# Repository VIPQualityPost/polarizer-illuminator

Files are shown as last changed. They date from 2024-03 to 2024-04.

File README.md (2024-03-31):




# Polarizer-Illuminator

A microscope illuminator that includes a liquid crystal display as a tunable polarizer. By polarizing the illuminator light, the reflected light can be filtered through a second polarizer (in this case the LCD) with specular reflections and glare removed, depending on the amount of polarization applied (based on bias across LCD). The illuminator is powered over USB PD and can be controlled via a PC for automated control in conjunctions with motorized XY stages and microscope camera. Firmware can be updated over same cable providing power thanks to DFU bootloader, just hold the button on the back and plug into a PC. 

Illuminator inspecting it's own board
| Non-polarized image | Polarized image |
| --- | --- |
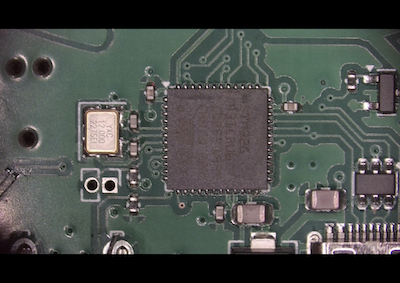
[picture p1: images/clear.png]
Image without polarization applied
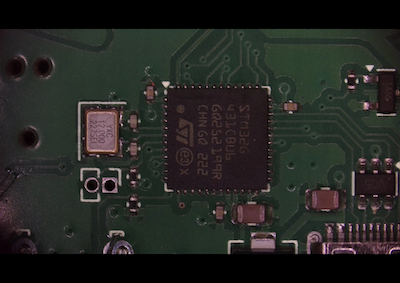
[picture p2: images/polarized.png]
Image with polarization applied
|  |  |

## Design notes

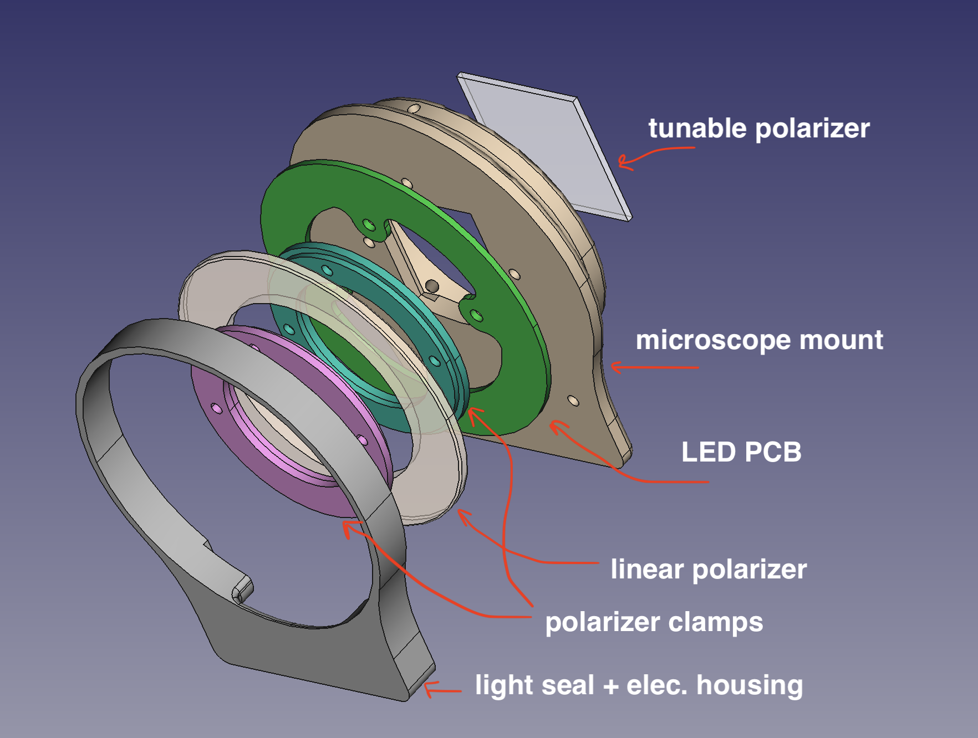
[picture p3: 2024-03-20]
mechanical/Screenshot 2024-03-01 at 9.00.45 PM.png

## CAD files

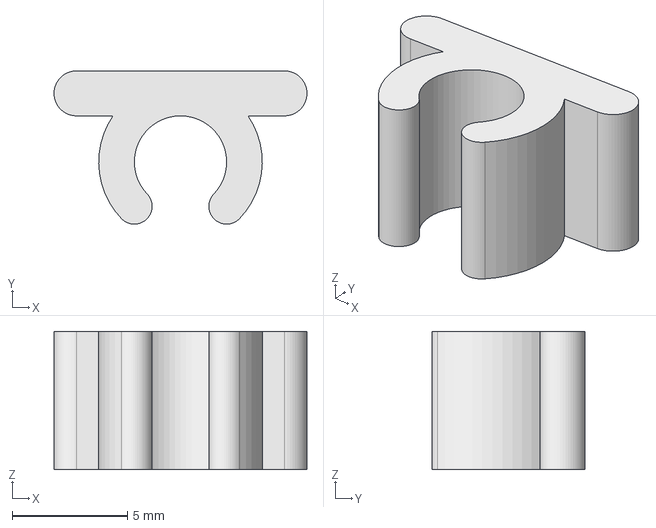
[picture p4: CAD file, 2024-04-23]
mechanical/cable-clamp.FCStd
11.0 x 6.64 x 6.00 mm

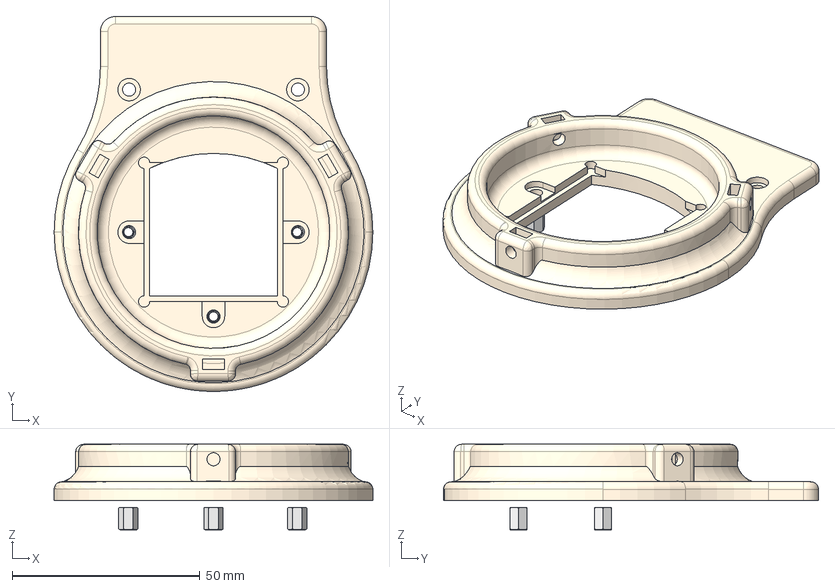
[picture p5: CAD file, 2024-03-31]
mechanical/illuminator.FCStd
85.0 x 100.0 x 22.8 mm
mount
95947A002_Aluminum Female Threaded Hex Standoff
95947A002_Aluminum Female Threaded Hex Standoff001
95947A002_Aluminum Female Threaded Hex Standoff002

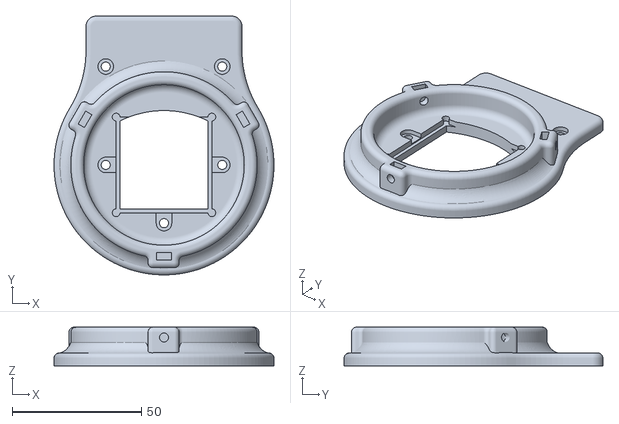
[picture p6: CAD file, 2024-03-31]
mechanical/illuminator-mount.stl
85.0 x 100.0 x 15.0

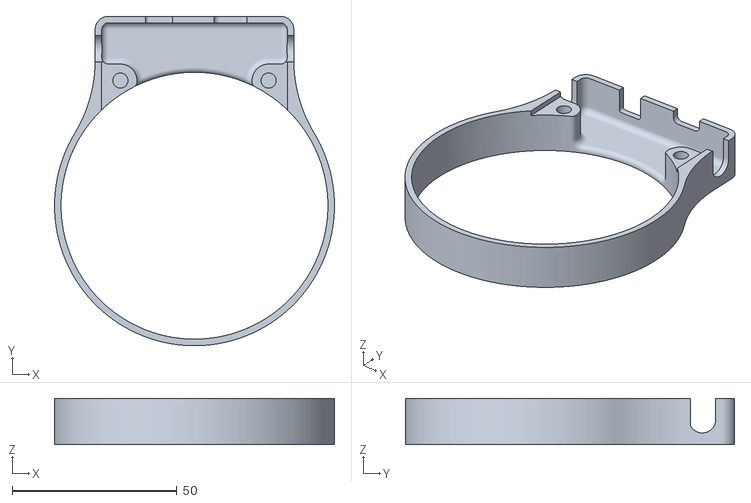
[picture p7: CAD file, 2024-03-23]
mechanical/illuminator-Shield.stl
85.0 x 100.0 x 14.0

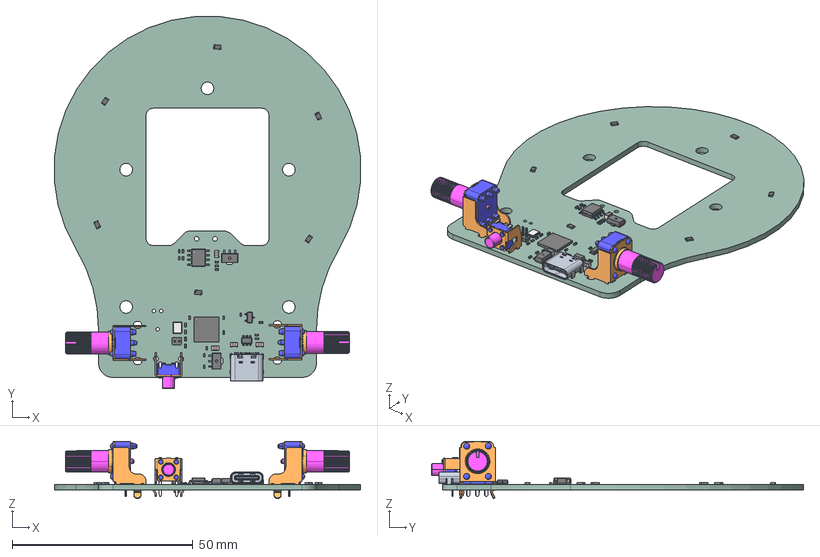
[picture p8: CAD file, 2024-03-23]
mechanical/illuminator-pcb.step
84.8 x 102.9 x 15.8 mm
C_0402_1005Metric x 13
SOT_23
R_0805_2012Metric x 6
R_0402_1005Metric x 8
C_0805_2012Metric x 4
SOIC_8_39x49mm_P127mm
TYPE-C-31-M-12
SOT_23_6
rk09k1110a0j x 2
PinHeader_1x02_P127mm_Vertical
QFN-48-1EP_7x7mm_Pitch0.5mm
CQ assembly x 2
Crystal_SMD_3225-4Pin_3.2x2.5mm
skhhlua010
illuminator_PCB

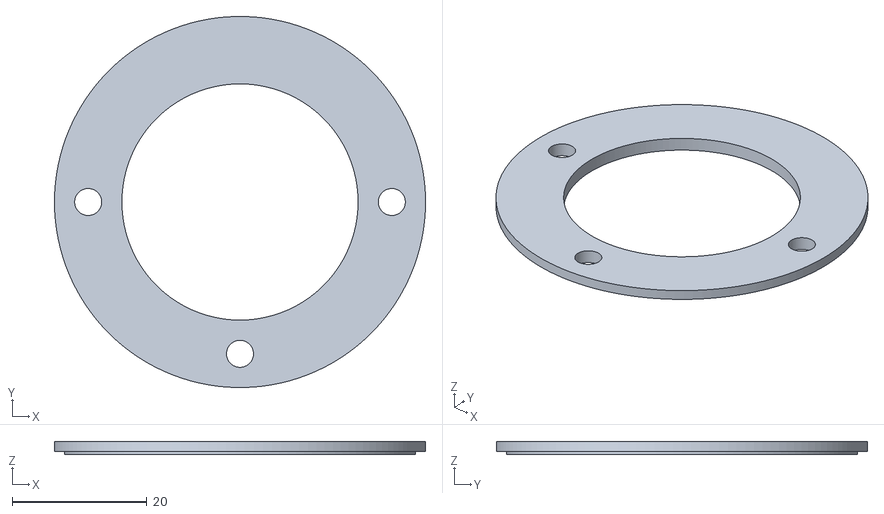
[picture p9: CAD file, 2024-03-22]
mechanical/illuminator-Clamp.stl
55.0 x 55.0 x 2.00

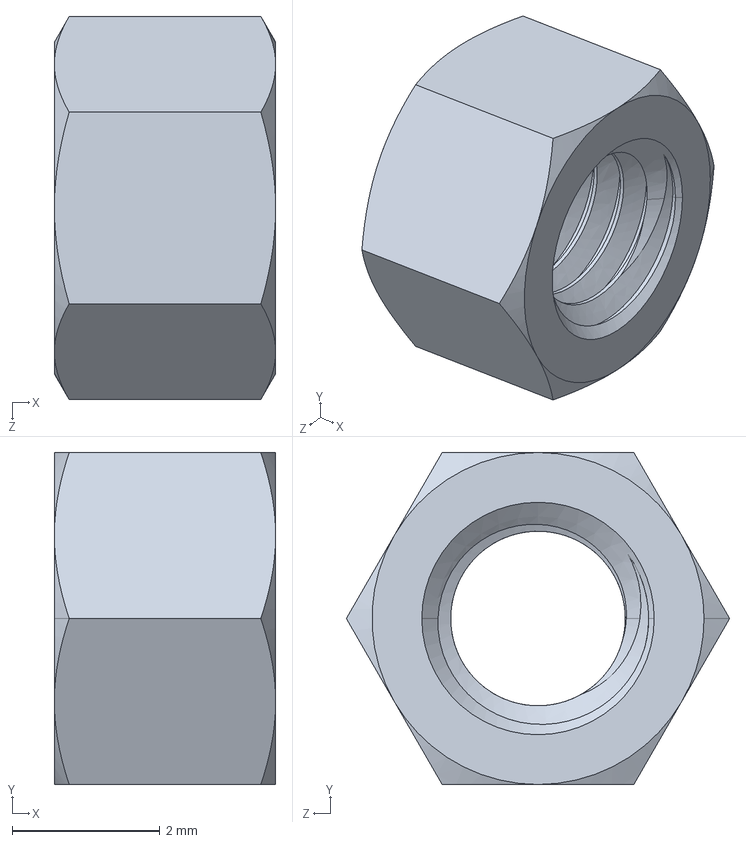
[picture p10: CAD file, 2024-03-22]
mechanical/95947A504_Aluminum Female Threaded Hex Standoff.STEP
3.00 x 4.50 x 5.20 mm

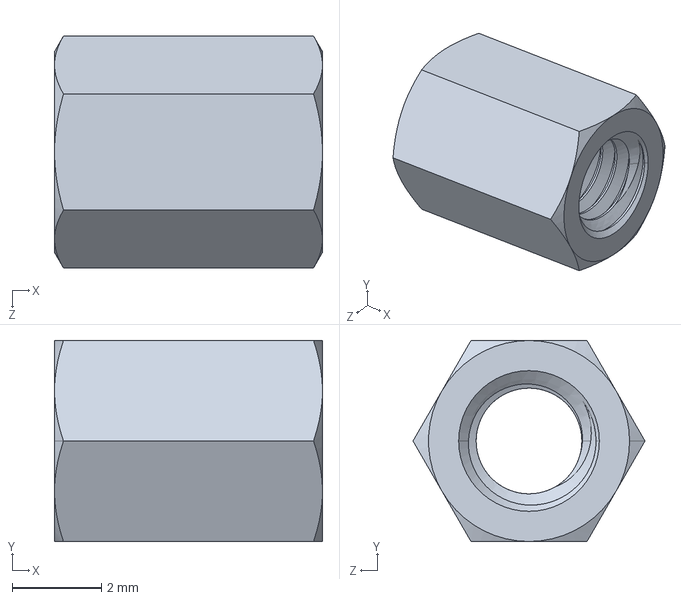
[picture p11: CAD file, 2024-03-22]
mechanical/95947A002_Aluminum Female Threaded Hex Standoff.STEP
6.00 x 4.50 x 5.20 mm

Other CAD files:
mechanical/cable-clamp.stl

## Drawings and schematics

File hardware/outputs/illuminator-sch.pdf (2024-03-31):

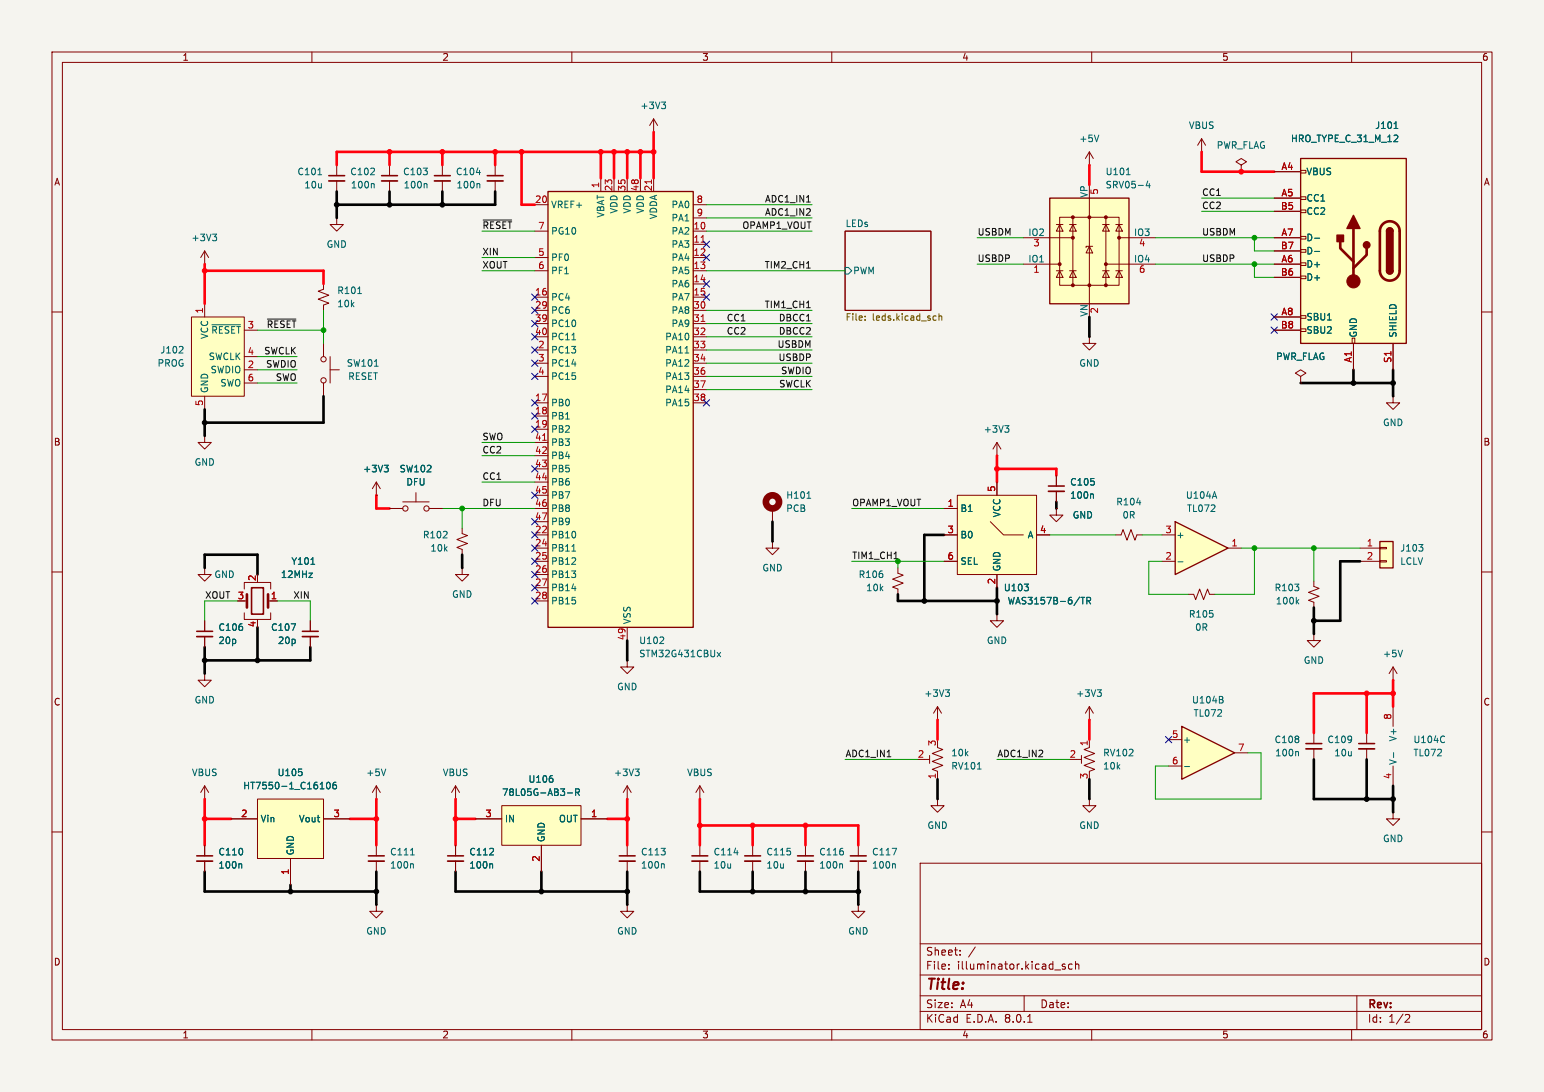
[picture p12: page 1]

1 PA2 10 PA3 11 PA4 12 PA5 13 PA6 14 PA7 15 PC4 16 PB0 17 PB1 18 PB2 19 PC13 2 VREF+ 20 VDDA 21 PB10 22 VDD 23 PB11 24 PB12 25 PB13 26 PB14 27 PB15 28 PC6 29 PC14 3 PA8 30 PA9 31 PA10 32 PA11 33 PA12 34 VDD 35 PA13 36 PA14 37 PA15 38 PC10 39 PC15 4 PC11 40 PB3 41 PB4 42 PB5 43 PB6 44 PB7 45 PB8 46 PB9 47 VDD 48 VSS 49 PF0 5 PF1 6 PG10 7 PA0 8 PA1 9 U102 STM32G431CBUx SWO

1 SWDIO 2 ~{RESET}3 SWCLK 4 GND
10k VCC

Id: 1/2 Title: File: illuminator.kicad_sch Sheet: /

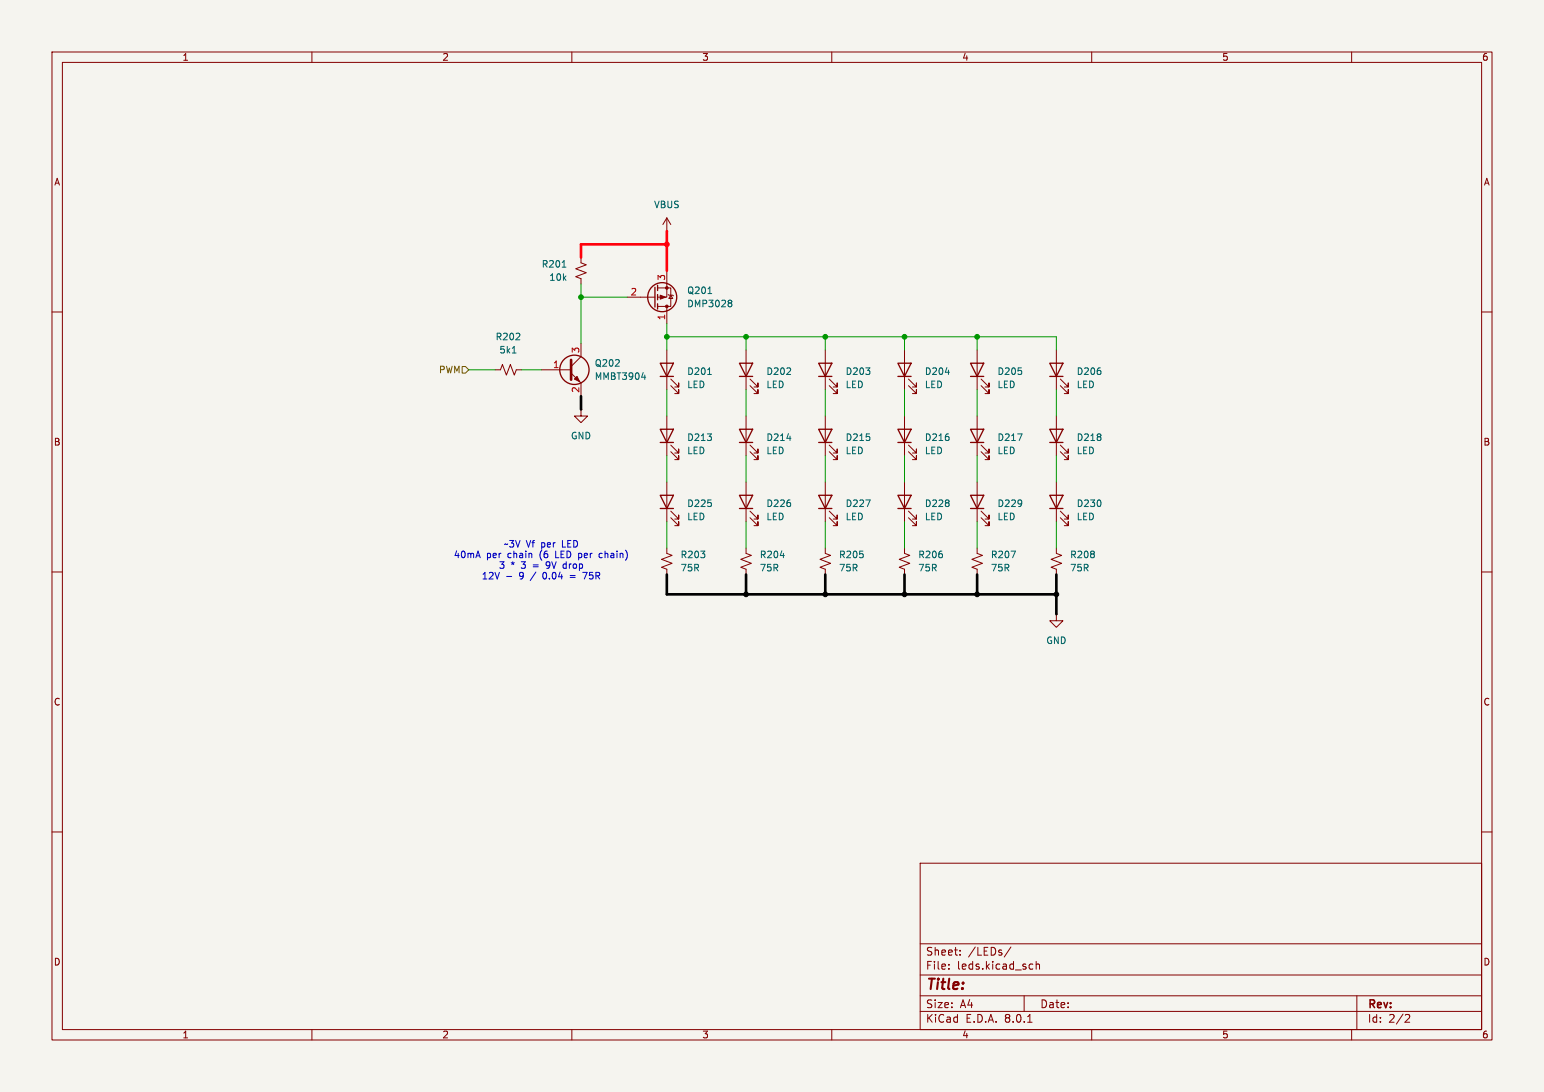
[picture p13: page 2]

Id: 2/2 Title: File: leds.kicad_sch Sheet: /LEDs/ D226
LED

40mA per chain (6 LED per chain) 3 * 3 = 9V drop

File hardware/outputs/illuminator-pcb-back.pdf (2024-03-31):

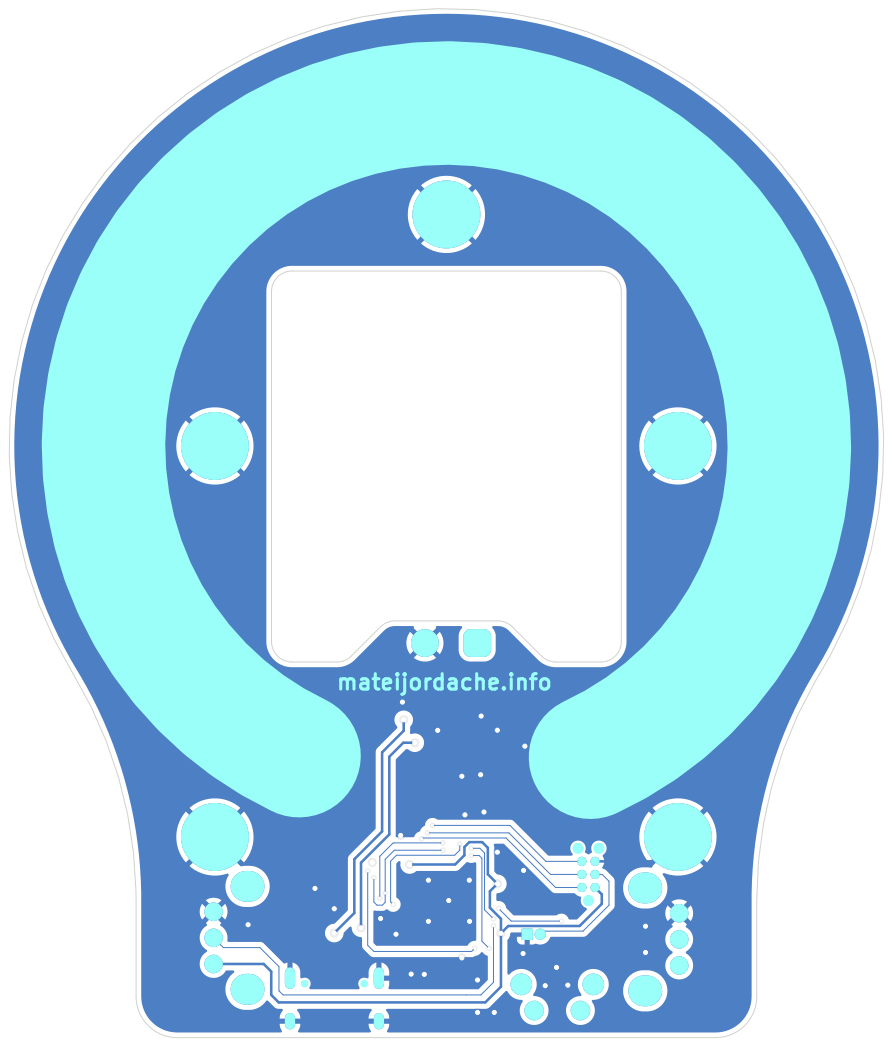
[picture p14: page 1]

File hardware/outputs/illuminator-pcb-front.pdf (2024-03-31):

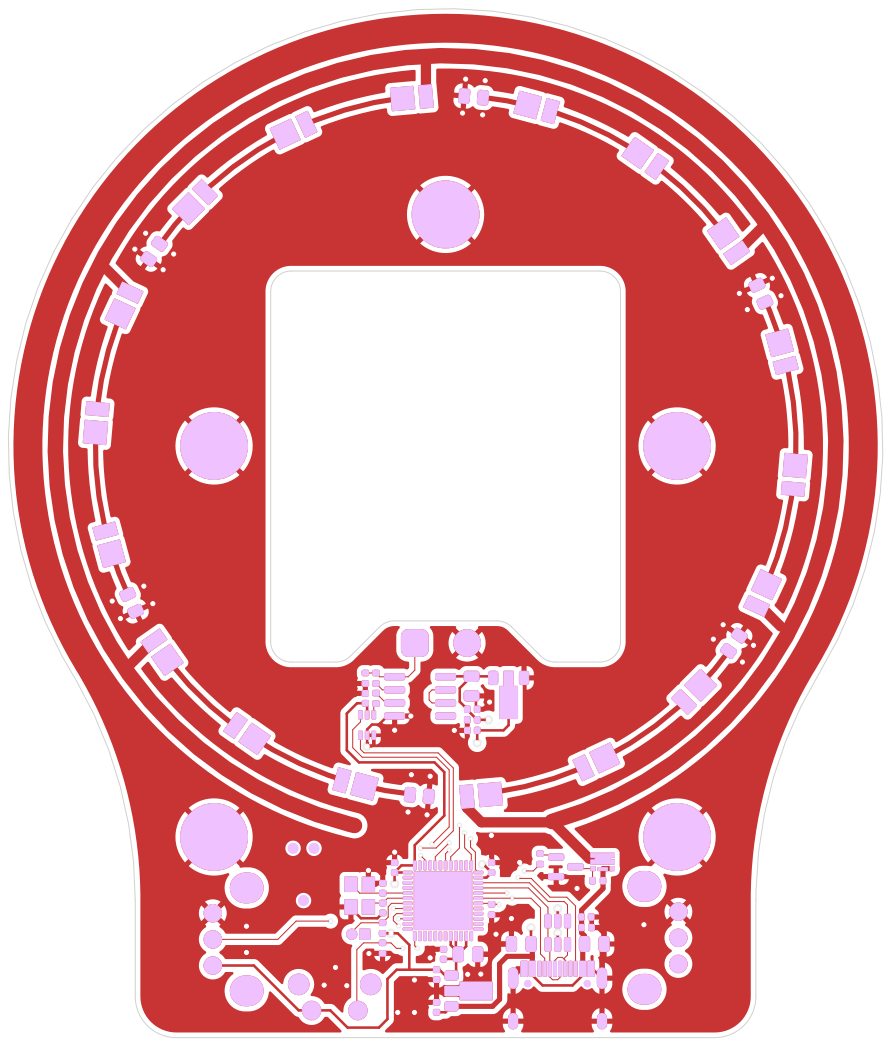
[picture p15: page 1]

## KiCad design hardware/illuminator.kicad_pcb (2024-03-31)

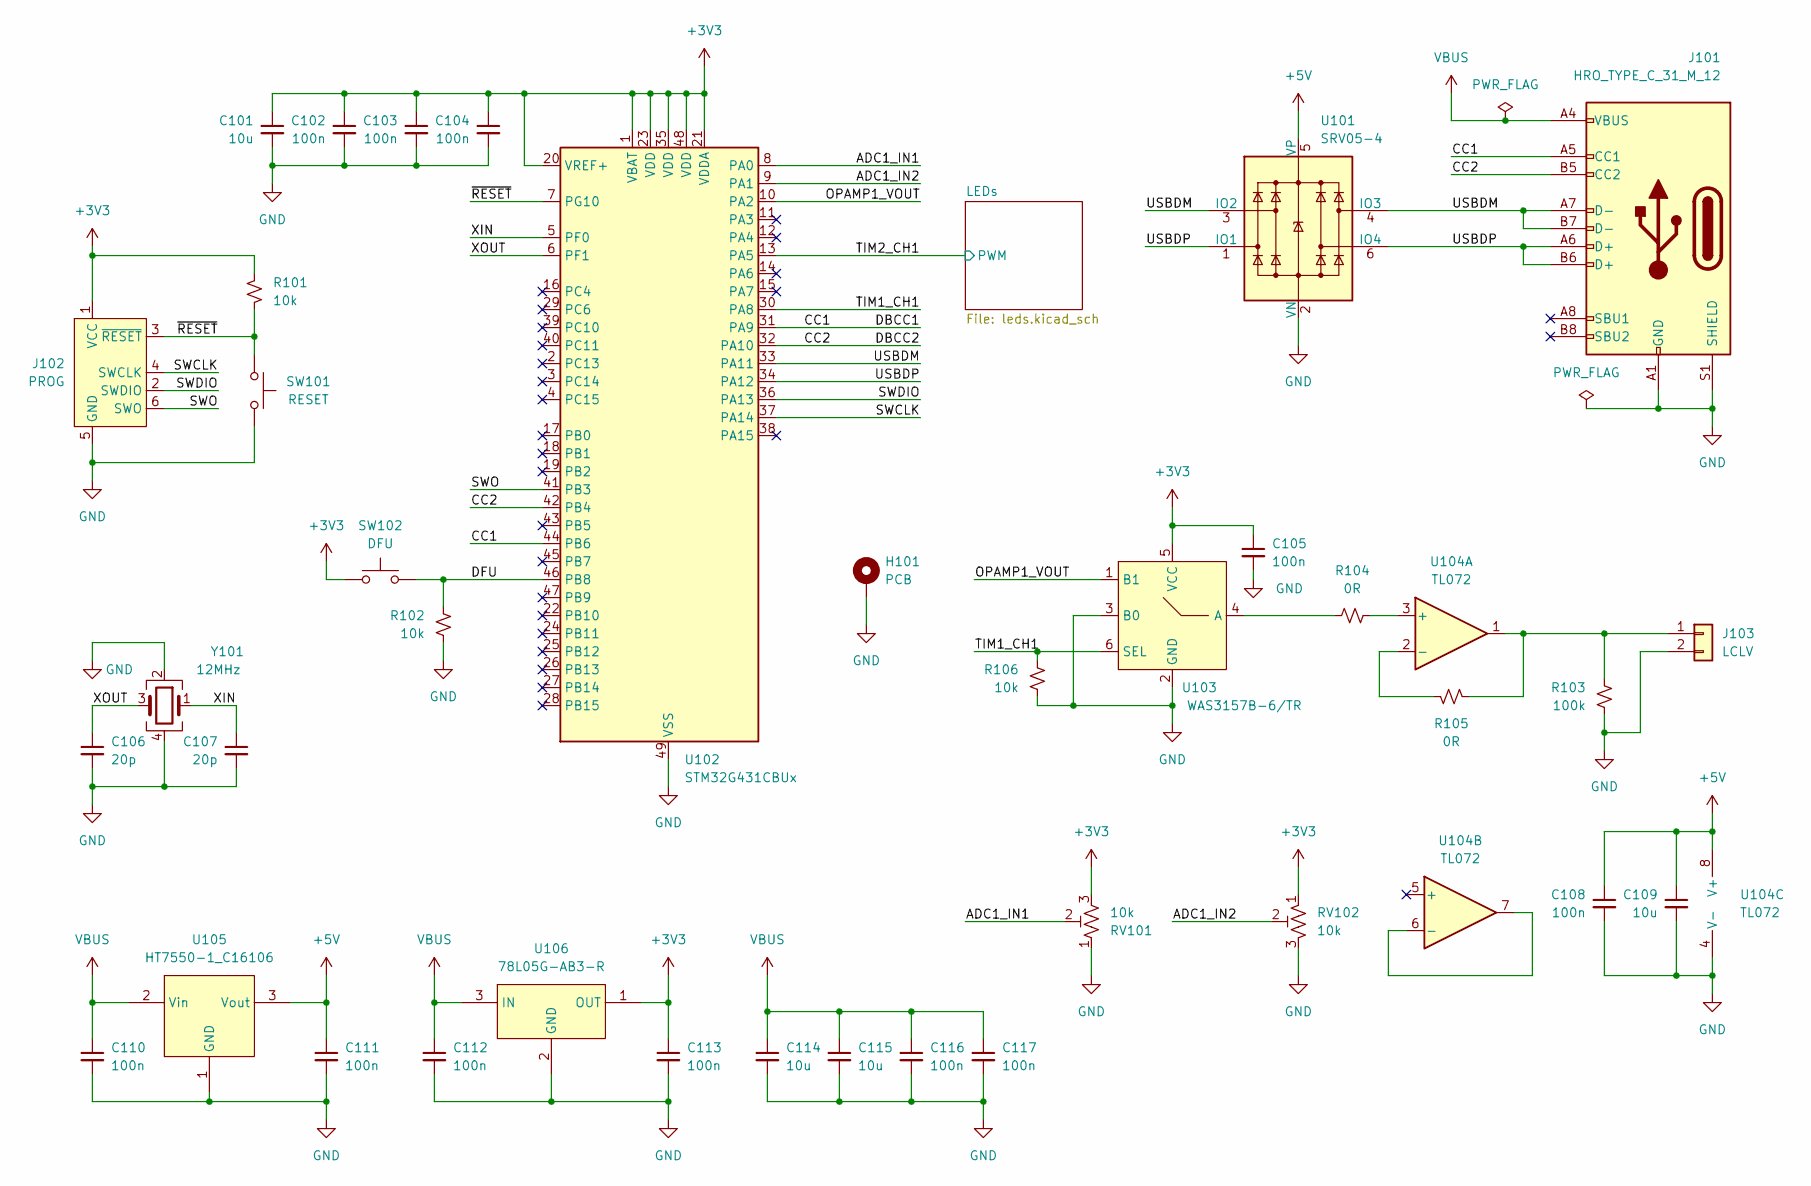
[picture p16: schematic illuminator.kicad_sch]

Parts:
C101, C109, C114, C115: 10u; C_0805_2012Metric; LCSC ID C440198
C102, C103, C104, C105, C108, C110, C111, C112, C113, C116, C117: 100n; C_0402_1005Metric; LCSC ID C307331
C106, C107: 20p; C_0402_1005Metric; LCSC ID C1554
H101: PCB; illuminator-monobody
J101: HRO_TYPE_C_31_M_12; USB_C_Receptacle_HRO_TYPE-C-31-M-12; LCSC ID C165948
J102: PROG; Tag-Connect_TC2030-IDC-NL_2x03_P1.27mm_Vertical
J103: LCLV; TestPoint_2Pads_Pitch5.08mm_Drill1.3mm
R101, R102, R106: 10k; R_0402_1005Metric; LCSC ID C25744
R103: 100k; R_0402_1005Metric; LCSC ID C25741
R104, R105: 0R; R_0402_1005Metric; LCSC ID C17168
RV101, RV102: 10k; RES-TH_RK09K1110A0J; LCSC ID C209767
SW101: RESET; PinHeader_1x02_P1.27mm_Vertical
SW102: DFU; KEY-TH_SKHHLWA010; LCSC ID C139764
U101: SRV05-4; SOT-23-6; LCSC ID C7420376
U102: STM32G431CBUx; QFN-48-1EP_7x7mm_P0.5mm_EP5.6x5.6mm; LCSC ID C529356
U103: WAS3157B-6/TR; SOT-363_L2.0-W1.3-P0.65-LS2.1-BL; LCSC ID C213161
U104: TL072; SOIC-8_3.9x4.9mm_P1.27mm; LCSC ID C6961
U105: HT7550-1_C16106; SOT-89-3; LCSC ID C16106
U106: 78L05G-AB3-R; SOT-89-3; LCSC ID C71136
Y101: 12MHz; Crystal_SMD_3225-4Pin_3.2x2.5mm; LCSC ID C9002

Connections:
+3V3: C101.1, C102.1, C103.1, C104.1, C105.1, C113.1, J102.1 (VCC), R101.1, RV101.3, RV102.1, SW102.1, U102.1 (VBAT), U102.20 (VREF+), U102.21 (VDDA), U102.23 (VDD), U102.35 (VDD), U102.48 (VDD), U103.5 (VCC), U106.1 (OUT)
+5V: C108.1, C109.1, C111.1, U101.5 (VP), U104.8 (V+), U105.3 (Vout)
/ADC1_IN1: RV101.2, U102.8 (PA0)
/ADC1_IN2: RV102.2, U102.9 (PA1)
/CC1: J101.A5 (CC1), U102.31 (PA9), U102.44 (PB6)
/CC2: J101.B5 (CC2), U102.32 (PA10), U102.42 (PB4)
/DFU: R102.1, SW102.2, U102.46 (PB8)
/OPAMP1_VOUT: U102.10 (PA2), U103.1 (B1)
/SWCLK: J102.4 (SWCLK), U102.37 (PA14)
/SWDIO: J102.2 (SWDIO), U102.36 (PA13)
/SWO: J102.6 (SWO), U102.41 (PB3)
/TIM1_CH1: R106.1, U102.30 (PA8), U103.6 (SEL)
/TIM2_CH1: U102.13 (PA5); also elsewhere on the board
/USBDM: J101.A7 (D-), J101.B7 (D-), U101.3 (IO2), U101.4 (IO3), U102.33 (PA11)
/USBDP: J101.A6 (D+), J101.B6 (D+), U101.1 (IO1), U101.6 (IO4), U102.34 (PA12)
/XIN: C107.1, U102.5 (PF0), Y101.1
/XOUT: C106.1, U102.6 (PF1), Y101.3
/~RESET: J102.3 (~RESET), R101.2, SW101.2, U102.7 (PG10)
GND: C101.2, C102.2, C103.2, C104.2, C105.2, C106.2, C107.2, C108.2, C109.2, C110.2, C111.2, C112.2, C113.2, C114.2, C115.2, C116.2, C117.2, H101.1, J101.A1 (GND), J101.A12 (GND), J101.B1 (GND), J101.B12 (GND), J101.S1 (SHIELD), J102.5 (GND), J103.2, R102.2, R103.2, R106.2, RV101.1, RV102.3, SW101.1, U101.2 (VN), U102.49 (VSS), U103.2 (GND), U103.3 (B0), U104.4 (V-), U105.1 (GND), U106.2 (GND), Y101.2, Y101.4; also elsewhere on the board
unnamed: J103.1, R103.1, R105.2, U104.1
unnamed: R104.1, U103.4 (A)
unnamed: R104.2, U104.3 (+)
unnamed: R105.1, U104.2 (-)
unnamed: U104.6 (-), U104.7
VBUS: C110.1, C112.1, C114.1, C115.1, C116.1, C117.1, J101.A4 (VBUS), J101.A9 (VBUS), J101.B4 (VBUS), J101.B9 (VBUS), U105.2 (Vin), U106.3 (IN); also elsewhere on the board

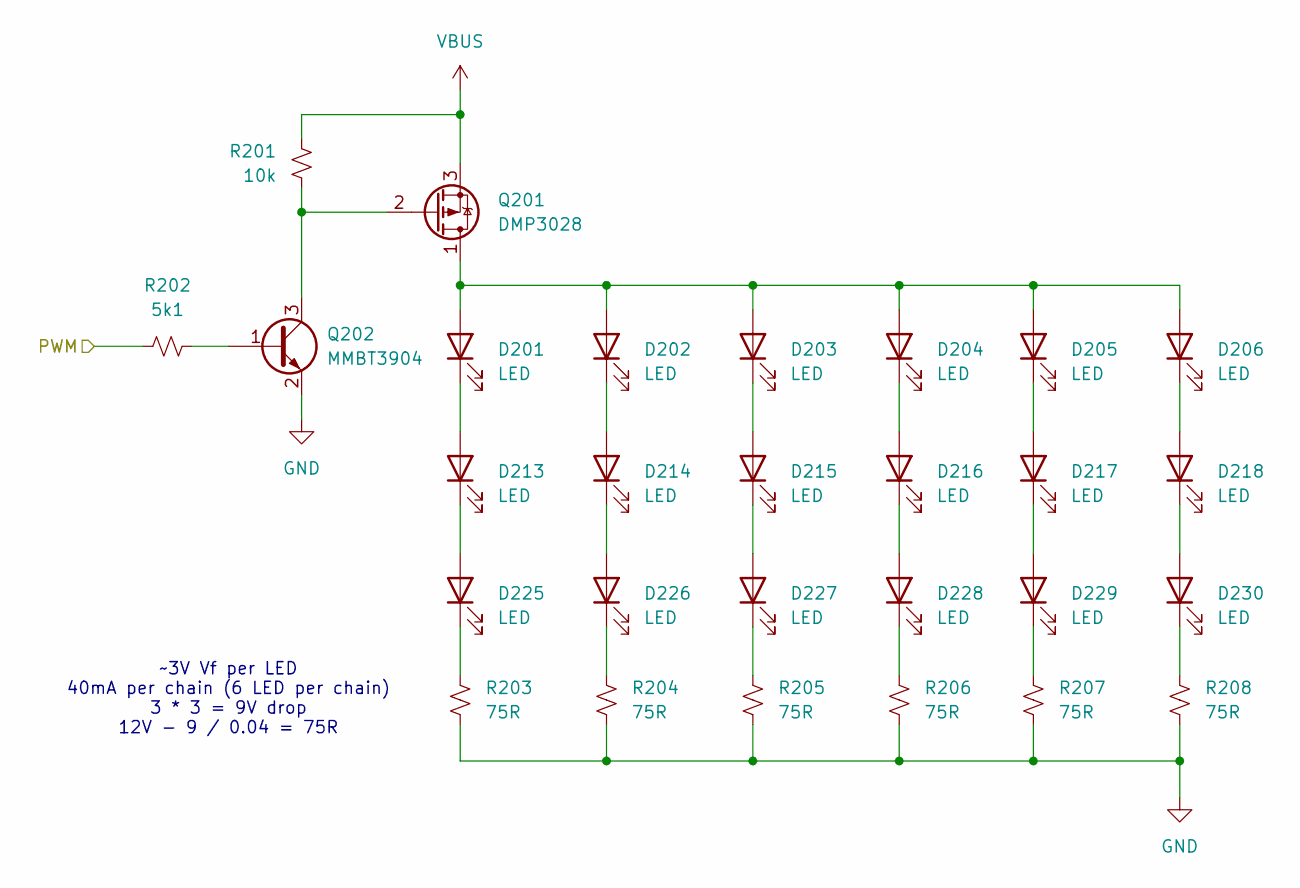
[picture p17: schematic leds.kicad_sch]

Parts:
D201, D202, D203, D204, D205, D206, D213, D214, D215, D216, D217, D218, D225, D226, D227, D228, D229, D230: LED; LED_PLCC_2835; LCSC ID C210312
Q201: DMP3028; DMP3028-UDFN2020; LCSC ID C150441
Q202: MMBT3904; SOT-23; LCSC ID C20526
R201: 10k; R_0402_1005Metric; LCSC ID C25744
R202: 5k1; R_0402_1005Metric; LCSC ID C25905
R203, R204, R205, R206, R207, R208: 75R; R_0805_2012Metric; LCSC ID C5198289

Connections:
/TIM2_CH1: R202.1; also elsewhere on the board
GND: Q202.2 (E), R203.2, R204.2, R205.2, R206.2, R207.2, R208.2; also elsewhere on the board
unnamed: D201.2 (A), D202.2 (A), D203.2 (A), D204.2 (A), D205.2 (A), D206.2 (A), Q201.1 (D)
unnamed: D201.1 (K), D213.2 (A)
unnamed: D202.1 (K), D214.2 (A)
unnamed: D203.1 (K), D215.2 (A)
unnamed: D204.1 (K), D216.2 (A)
unnamed: D205.1 (K), D217.2 (A)
unnamed: D206.1 (K), D218.2 (A)
unnamed: D213.1 (K), D225.2 (A)
unnamed: D214.1 (K), D226.2 (A)
unnamed: D215.1 (K), D227.2 (A)
unnamed: D216.1 (K), D228.2 (A)
unnamed: D217.1 (K), D229.2 (A)
unnamed: D218.1 (K), D230.2 (A)
unnamed: D225.1 (K), R203.1
unnamed: D226.1 (K), R204.1
unnamed: D227.1 (K), R205.1
unnamed: D228.1 (K), R206.1
unnamed: D229.1 (K), R207.1
unnamed: D230.1 (K), R208.1
unnamed: Q201.2 (G), Q202.3 (C), R201.2
unnamed: Q202.1 (B), R202.2
VBUS: Q201.3 (S), R201.1; also elsewhere on the board

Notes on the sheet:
~3V Vf per LED 40mA per chain (6 LED per chain) 3 * 3 = 9V drop 12V - 9 / 0.04 = 75R

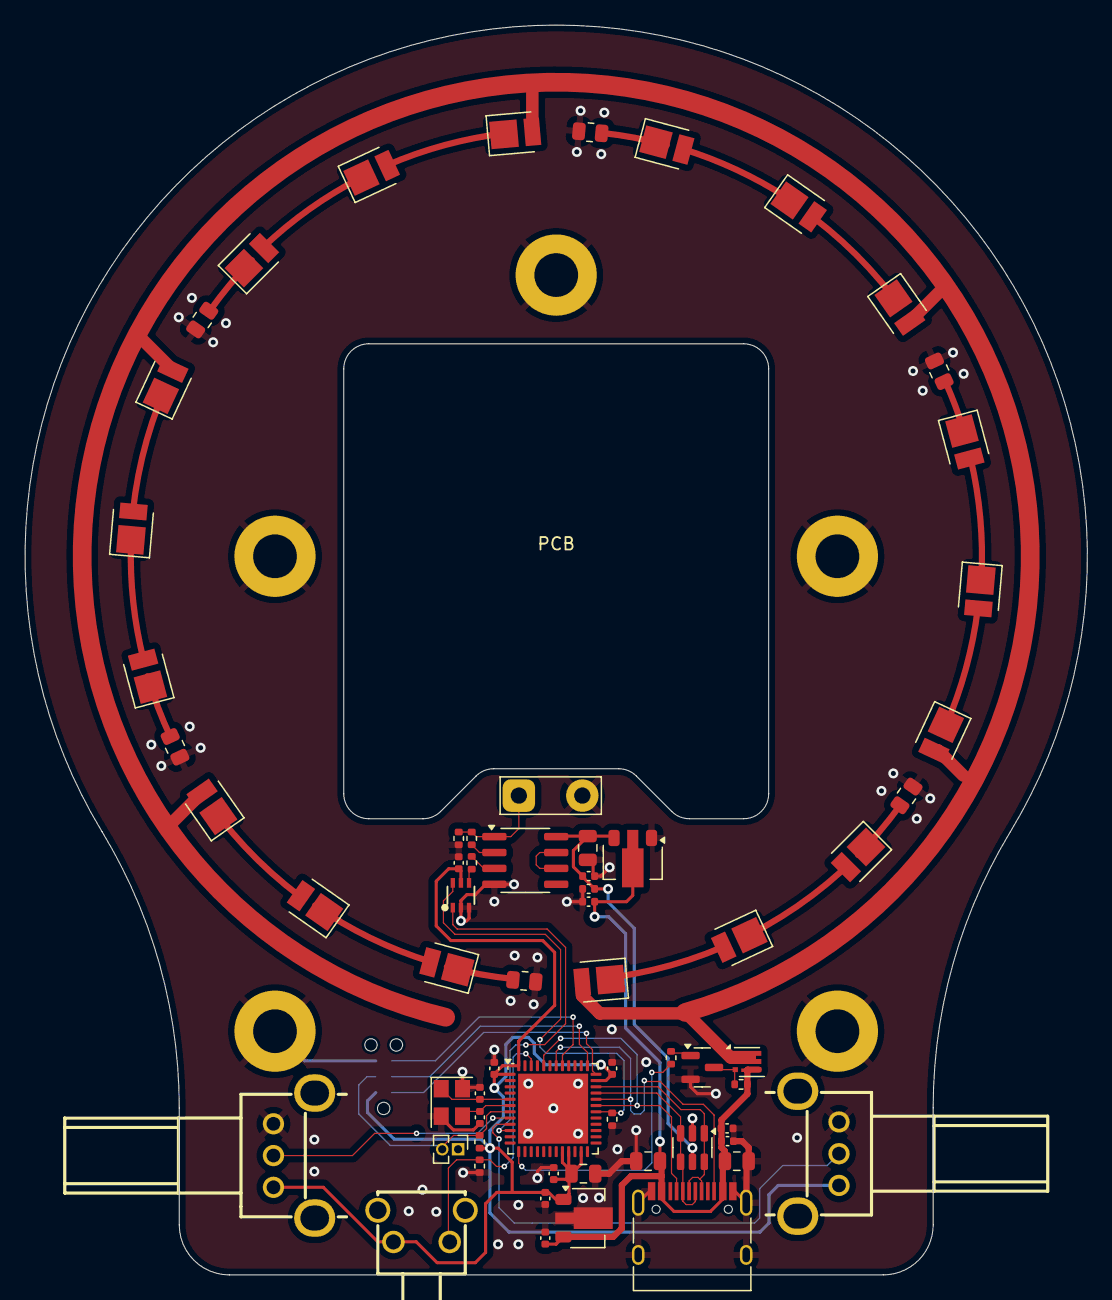
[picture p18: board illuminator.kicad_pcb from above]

Board: 4 copper layers, 85.0 x 100.0 mm, 66 parts (1 on the bottom side), 46 nets.

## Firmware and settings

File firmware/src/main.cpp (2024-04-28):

#include <Arduino.h>
#include "adc.h"
#include "dac.h"
#include "dma.h"
#include "opa.h"

#include "stm32g4xx_hal.h"
#include "stm32g4xx_hal_adc.h"
#include "stm32g4xx_hal_dac.h"
#include "stm32g4xx_hal_dma.h"
#include "stm32g4xx_hal_opamp.h"

#include "RTTStream.h"
#include "PeripheralPins.h"
#include "USBPowerDelivery.h"

#define USBD_MANUFACTURER_STRING "matei repair lab"
#define USBD_PRODUCT_STRING_FS "illuminator"

extern ADC_HandleTypeDef hadc1;
extern DAC_HandleTypeDef hdac3;
extern OPAMP_HandleTypeDef hopamp1;

RTTStream rtt;

bool IlluminatorEnabled = true;
bool togglePolarizer = true;

volatile uint16_t adc_data[2] = {0};

void userButton(void){
  if(IlluminatorEnabled){
    PowerSink.requestPower(5000, 2000);
    DAC3->CR &= ~DAC_CR_CEN1;
  }
  else{
    PowerSink.requestPower(15000, 2000);
    DAC3->CR |= DAC_CR_CEN1;
  }

  IlluminatorEnabled = !IlluminatorEnabled;
}

void updateControls(void){
  if(togglePolarizer)
    DAC3->DHR12R1 = 0x000;
  else
    DAC3->DHR12R1 = analogRead(LEFT_POT) << 2;

  TIM2->CCR1 = analogRead(RIGHT_POT) << 6;
  togglePolarizer = !togglePolarizer;
}

void handlePDEvent(PDSinkEventType evt){
  if(evt == PDSinkEventType::sourceCapabilitiesChanged){
    // Search for 15V PDO
    for(int i = 0; i < PowerSink.numSourceCapabilities; i+= 1){
      if(PowerSink.sourceCapabilities[i].minVoltage <= 15000 && 
        PowerSink.sourceCapabilities[i].maxVoltage >=15000){
          PowerSink.requestPower(15000);
          return;
      }
    }
    // Try for 12V if no 15V PDO
    for(int i = 0; i < PowerSink.numSourceCapabilities; i += 1){
      if(PowerSink.sourceCapabilities[i].minVoltage <= 12000 &&
        PowerSink.sourceCapabilities[i].maxVoltage >=12000){
          PowerSink.requestPower(12000);
          return;
      }
    }

  PowerSink.requestPower(9000);
  }

}

void setup() {
  pinMode(USER_BUTTON, INPUT);
  pinMode(LEFT_POT, INPUT_ANALOG);
  pinMode(RIGHT_POT, INPUT_ANALOG);
  pinMode(LED_PWM, OUTPUT);
  pinMode(LCD_PWM, OUTPUT);
  pinMode(LCD_OPA, OUTPUT);

  PowerSink.start();
  PowerSink.requestPower(9000);
  PowerSink.requestPower(12000);
  PowerSink.requestPower(15000);

  // digitalWrite(LED_PWM, HIGH);

  // __HAL_RCC_DMAMUX1_CLK_ENABLE();
  // __HAL_RCC_DMA1_CLK_ENABLE();

  // gpio_config_adc(&hadc1);
  // init_adc();
  // HAL_ADC_Start_DMA(&hadc1, (uint32_t*)adc_data, 2);

  __HAL_RCC_DAC3_CLK_ENABLE();
  init_dac();

  gpio_config_opa(&hopamp1);
  init_opa();
  
  HAL_OPAMP_Start(&hopamp1);
  HAL_DAC_Start(&hdac3, DAC_CHANNEL_1);
  
  TIM_TypeDef* IlluminatorTimer = TIM2;
  uint32_t IlluminatorChannel = STM_PIN_CHANNEL(pinmap_function(digitalPinToPinName(LED_PWM), PinMap_PWM));
  HardwareTimer* Illuminator = new HardwareTimer(IlluminatorTimer);
  Illuminator->setMode(IlluminatorChannel, TIMER_OUTPUT_COMPARE_PWM1, LED_PWM);
  Illuminator->setOverflow(5000, HERTZ_FORMAT);

  TIM_TypeDef *PolarizerTimer = TIM1;
  HardwareTimer* Polarizer = new HardwareTimer(PolarizerTimer);
  Polarizer->attachInterrupt(updateControls);
  Polarizer->setOverflow(1000, HERTZ_FORMAT);

  Illuminator->resume();
  Polarizer->resume();

  attachInterrupt(PB8, userButton, RISING);
}

void loop(){ 
}

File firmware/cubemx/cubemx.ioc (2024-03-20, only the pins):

Mcu.UserName=STM32G431CBUx
PA0.Signal=ADC1_IN1
PA1.Signal=ADC1_IN2
PA10.Signal=UCPD1_DBCC2
PA11.Signal=USB_DM
PA12.Signal=USB_DP
PA13.Signal=SYS_JTMS-SWDIO
PA14.Signal=SYS_JTCK-SWCLK
PA2.Signal=OPAMP1_VOUT
PA5.Signal=S_TIM2_CH1
PA8.Signal=S_TIM1_CH1
PA9.Signal=UCPD1_DBCC1
PB3.Signal=SYS_JTDO-SWO
PB4.Signal=UCPD1_CC2
PB6.Signal=UCPD1_CC1
PF0-OSC_IN.Signal=RCC_OSC_IN
PF1-OSC_OUT.Signal=RCC_OSC_OUT

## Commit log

2024-03-20 fix erc errors
    [illuminator.FCStd, illuminator.kicad_sch, leds.kicad_sch]
2024-03-20 fix bom
    [illuminator.kicad_pcb, leds.kicad_sch]
2024-03-20 add gain resistors
    [illuminator.kicad_pcb, illuminator.kicad_sch]
2024-03-20 fix drc
    [illuminator.kicad_pcb, illuminator.kicad_sch]
2024-03-20 fix zones
    [illuminator.kicad_pcb]
2024-03-22 update mechanical design and add tinyusb USB PD
    [95947A002_Aluminum Female Threaded Hex Standoff.STEP, 95947A504_Aluminum Female Threaded Hex Standoff.STEP, illuminator-Clamp.stl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]
2024-03-23 Update CI and mechanical assembly
    [illuminator-Shield.stl, illuminator-mount.stl, illuminator-pcb.step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]
2024-03-23 mechanical update
    [illuminator-Shield.stl, illuminator-mount.stl, illuminator.FCStd]
2024-03-31 basic functionality working
    [illuminator-mount.stl, illuminator.FCStd, illuminator.kicad_pcb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]
2024-03-31 fix dma channel conflict
    [adc.cpp, main.cpp]
2024-04-05 dma working but still crashing
    [adc.cpp, main.cpp]
2024-04-23 add cable clamps
    [cable-clamp.FCStd, cable-clamp.stl]
